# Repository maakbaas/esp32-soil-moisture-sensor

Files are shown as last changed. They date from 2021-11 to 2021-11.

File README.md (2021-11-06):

# ESP32 Soil Moisture Sensor
Software and Gerber files for a simple soil moisture sensor using the ESP32 and a bistable status indicator.

More information on the project:
* https://maakbaas.com/esp32-soil-moisture-sensor/logs/logging-to-the-cloud/
* https://hackaday.com/2021/10/28/soil-sensor-shows-flip-dots-arent-just-for-signs/

## Known issues:

* The sensor functionality degraded for me after a few months in use. My hypothesis is that this is due to the PCB material soaking up moisture over time. If this hypothesis is correct, one way to prevent it would be to add epoxy around the PCB edges
* By mistake there is a ground plane underneath the ESP32 Antenna, this should be removed for better WiFi performance
* The code does not do well if there are WiFi connectivity issues. It will try to reconnect until the battery is drained
* Maximum real world battery life I have seen is around 4 months, but solving the previous point might lengthen that

## Photo:

PCB

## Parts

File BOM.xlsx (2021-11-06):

Id | Designator | Package | Quantity | Designation | Supplier and ref | Column1 | _1
2 | U2,U1 | 53 | 2 | Keystone 534-553
4 | SW1 | SW_SPST_PTS810 | 1 | C&K PTS810SJG250SMTRLFS
5 | IC2 | SOP100P600X175-10N | 1 | LB1930MC-AH
6 | IC1 | ESP32WROVERM203QL3264PH3Q0 | 1 | ESP32-WROVER | Must be WROVER module, it is the only module which works down to 1.8v
7 | J1 | PinHeader_1x04_P2.54mm_Vertical | 1 | For ESP32 Flashing
8 | J2 | PinHeader_1x02_P2.54mm_Vertical | 1 | Indicator Alfa Zeta C30NR in red/green
9 | R1 | R_0603_1608Metric | 1 | 10K
10 | C3 | C_0603_1608Metric | 1 | 10uF
11 | C2,C1 | C_0603_1608Metric | 2 | 0.1uF

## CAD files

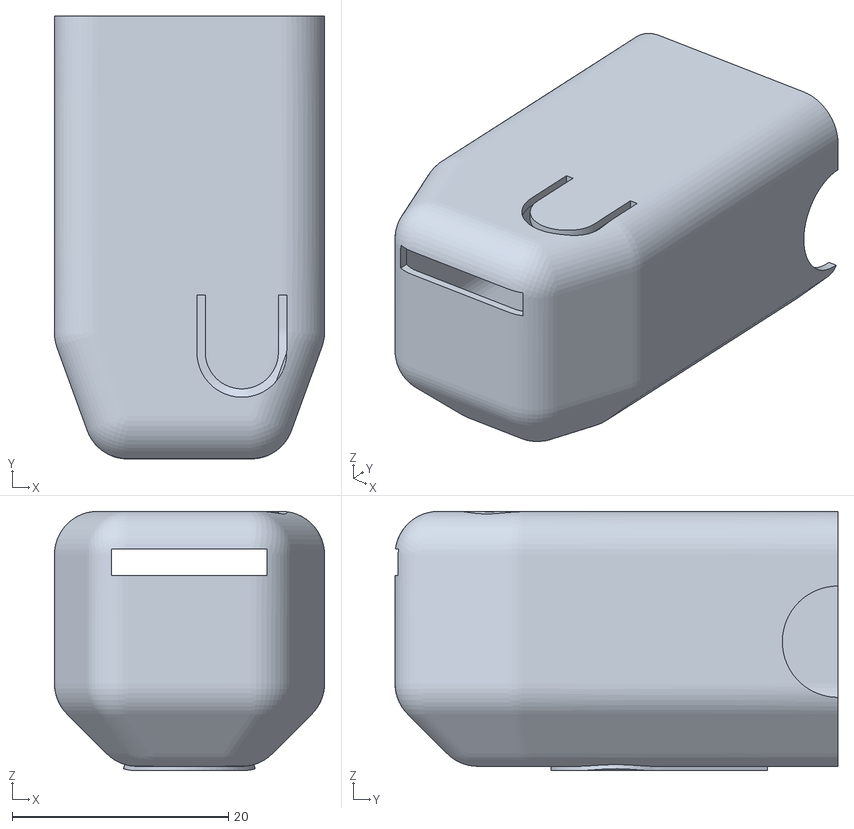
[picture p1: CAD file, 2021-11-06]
Case.stl
25.0 x 41.0 x 24.0

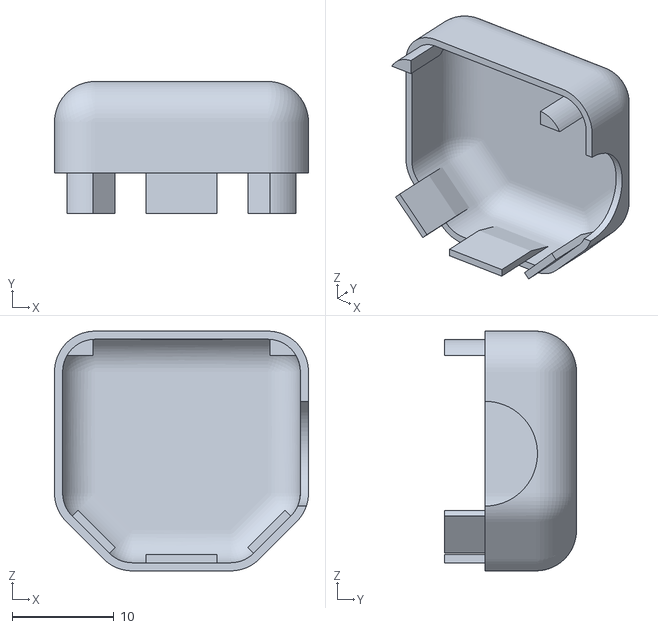
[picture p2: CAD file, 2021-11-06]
Cap.stl
25.0 x 13.0 x 23.6

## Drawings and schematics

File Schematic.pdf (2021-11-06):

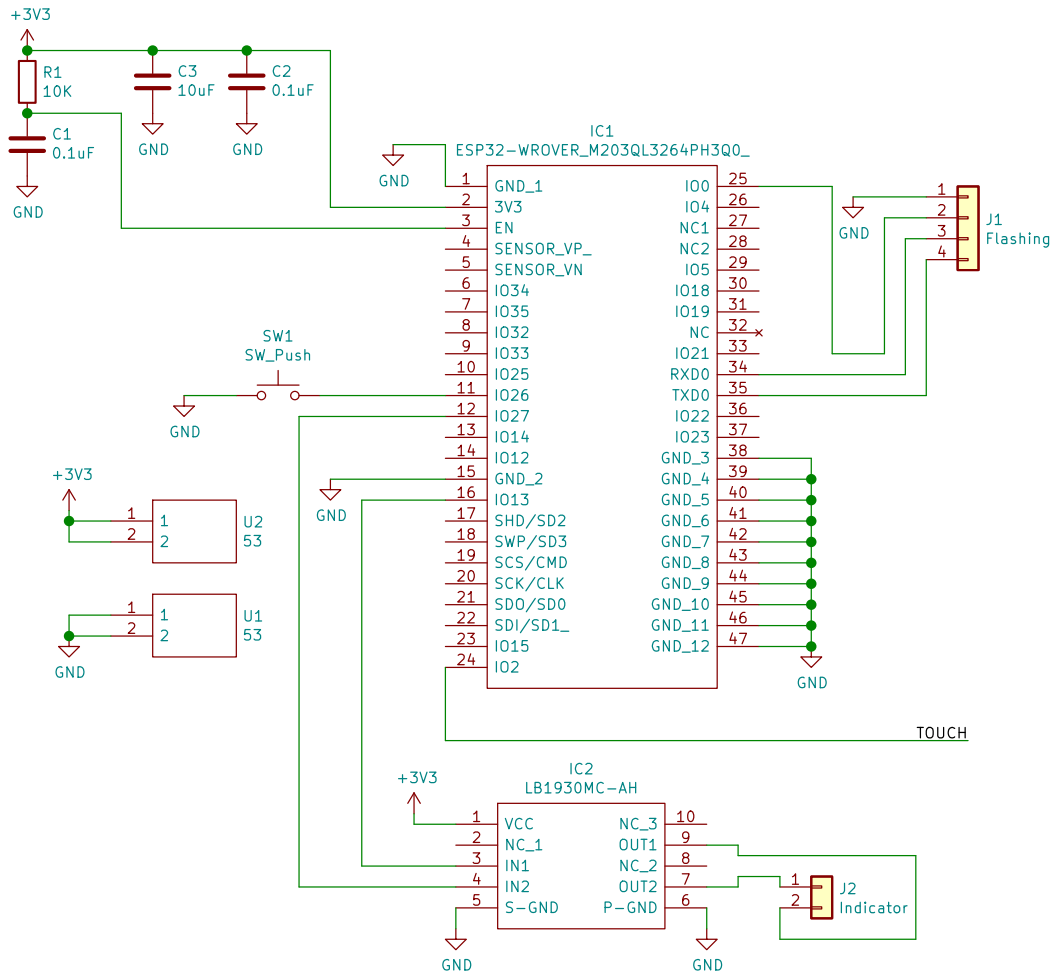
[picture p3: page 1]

File: plant.sch Sheet: /

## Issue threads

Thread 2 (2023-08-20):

src/main.cpp:54:3: error: 'touch_pad_config' was not declared in this scope

Diaver, 2023-08-20:
Hey!
Trying build you project, but not able to do it because missing touch_pad functions.
Can you please help with it?

Thanks!

Diaver, 2023-08-20:
Was needed add #include "driver/touch_pad.h"

Closed 2023-08-20.

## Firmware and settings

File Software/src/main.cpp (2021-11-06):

#include <Arduino.h>
#include <Preferences.h>
#include <WiFi.h>
#include "time.h"
#include <HTTPClient.h>

#define DEBUG

Preferences preferences;

enum status_e{UNKNOWN, RED, GREEN}; 

#ifdef DEBUG
    RTC_DATA_ATTR int bootCount = 0;
#endif
RTC_DATA_ATTR uint16_t threshold = 0;
RTC_DATA_ATTR enum status_e status;

RTC_DATA_ATTR uint16_t measBuffer[24];
RTC_DATA_ATTR uint16_t thresholdBuffer[24];
RTC_DATA_ATTR uint32_t timestampBuffer[24];
RTC_DATA_ATTR uint8_t bufferIndex = 0;

void initWiFi() {
  WiFi.mode(WIFI_STA);
  WiFi.begin("WIFI_SSID", "WIFI_PASSWORD");
  #ifdef DEBUG
    Serial.print("Connecting to WiFi ..");
  #endif
  uint8_t timeout = 0;
  while (WiFi.status() != WL_CONNECTED) {
    delay(1000);
    timeout++;
    if (timeout==10)
        ESP.restart();
  }
  #ifdef DEBUG
    Serial.println(WiFi.localIP());
  #endif
}

void setup() {
    
  // put your setup code here, to run once:
  pinMode(GPIO_NUM_13,OUTPUT);
  pinMode(GPIO_NUM_27,OUTPUT);
  pinMode(GPIO_NUM_26,INPUT_PULLUP);
  #ifdef DEBUG
    Serial.begin(115200);
  #endif

  touch_pad_init();
  touch_pad_set_voltage(TOUCH_HVOLT_2V4, TOUCH_LVOLT_0V5, TOUCH_HVOLT_ATTEN_1V);
  touch_pad_config(TOUCH_PAD_NUM2, 0);
  
  //do measurement 
  uint16_t output;
  touch_pad_read(TOUCH_PAD_NUM2,&output);

  esp_sleep_wakeup_cause_t wakeup_reason;
  wakeup_reason = esp_sleep_get_wakeup_cause();

  switch(wakeup_reason)
  {
    case ESP_SLEEP_WAKEUP_EXT0 : 
        #ifdef DEBUG
            Serial.println("Wakeup caused by external signal using RTC_IO"); 
        #endif

        //debounce button press
        delay(1000);

        //set threshold to current value      
        threshold = output - 5;
        preferences.begin("nvm", false); 
        preferences.putUShort("threshold",threshold);
        preferences.end();

        if (status!=RED)
        {
            //set to red
            digitalWrite(GPIO_NUM_13,HIGH);
            delay(500);
            digitalWrite(GPIO_NUM_13,LOW); 
            status = RED;
        }

        break;
    case ESP_SLEEP_WAKEUP_TIMER : 
        #ifdef DEBUG
            Serial.println("Wakeup caused by timer"); 
        #endif

        //write buffers
        time_t now;
        time(&now);
        timestampBuffer[bufferIndex] = now;
        thresholdBuffer[bufferIndex] = threshold;
        measBuffer[bufferIndex] = output;
        bufferIndex++;

        if (bufferIndex == 24 || (output > threshold && status!=RED))
        {
            //write to DB daily or when watering is needed            
            initWiFi();

            HTTPClient http;
            http.begin("http://192.168.1.90:8086/write?db=plant&u=admin&p=admin");
            http.addHeader("Content-Type", "application/binary");

            char payload[2000], *pos = payload;

            for(int i=0; i<bufferIndex; i++)
            {
                pos += sprintf(pos,"moisture2 level=%d,threshold=%d %d000000000\n",measBuffer[i],thresholdBuffer[i],timestampBuffer[i]);
            }    

            http.POST((uint8_t *)payload, strlen(payload));
            http.end();

            bufferIndex=0;     
        }

        //check the sensor
        if (output > threshold && status!=RED)
        {
            //set to red
            digitalWrite(GPIO_NUM_13,HIGH);
            delay(500);
            digitalWrite(GPIO_NUM_13,LOW); 
            status = RED;
        } 
        else if (output <= threshold && status!=GREEN)  
        {
            //set to green
            digitalWrite(GPIO_NUM_27,HIGH);
            delay(500);
            digitalWrite(GPIO_NUM_27,LOW);
            status = GREEN;
        }

        break;
    default : 
        //do not check the sensor, since the battery is just placed, it can be that it is not placed in the soil
        #ifdef DEBUG
            Serial.printf("Wakeup was not caused by deep sleep: %d\n",wakeup_reason); 
        #endif

        //read EEPROM
        preferences.begin("nvm", true); 
        threshold = preferences.getUShort("threshold");
        preferences.end();

        //set real time clock
        initWiFi();
        configTime(0, 0, "pool.ntp.org");   
        struct tm timeinfo;
        getLocalTime(&timeinfo);
        
        break;
  }

  esp_sleep_enable_ext0_wakeup(GPIO_NUM_26, 0);
  #ifdef DEBUG
    // esp_sleep_enable_timer_wakeup(5000000);
    esp_sleep_enable_timer_wakeup(3600000000);
  #else
    esp_sleep_enable_timer_wakeup(3600000000);
  #endif

  #ifdef DEBUG
    Serial.printf("Sensor value: %d\n",output);
    Serial.printf("Threshold value: %d\n",threshold);
    Serial.printf("Cycle count: %d\n",bootCount);  
    bootCount++;
  #endif

  esp_deep_sleep_start();

}

void loop() {

  // no loop

}
